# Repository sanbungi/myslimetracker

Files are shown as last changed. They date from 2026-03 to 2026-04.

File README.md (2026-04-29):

# 3次元移動解析装置 改 — 乾電池駆動 SlimeVR トラッカー

VR ヘッドセットだけでは追跡できない足や腰の動きを取るための、自作 SlimeVR 互換フルボディトラッカーです。両足先・両膝・腰・胸の6点に装着し、VRChat 上でのフルトラッキングを実現しています。

- 単3乾電池駆動 — リチウムポリマー電池のリスクを避け、安全で入手しやすい乾電池で動作
- 最上級 IMU 搭載 — SlimeVR 対応 IMU の中で最高性能の LSM6DSV を採用
- 低コスト — mocopi（5万円〜）に対し、6トラッカーを合計約2万円で制作
- 高い拡張性 — SlimeVR はトラッカー数に制限がなく、必要に応じて増設可能

<p align="center">
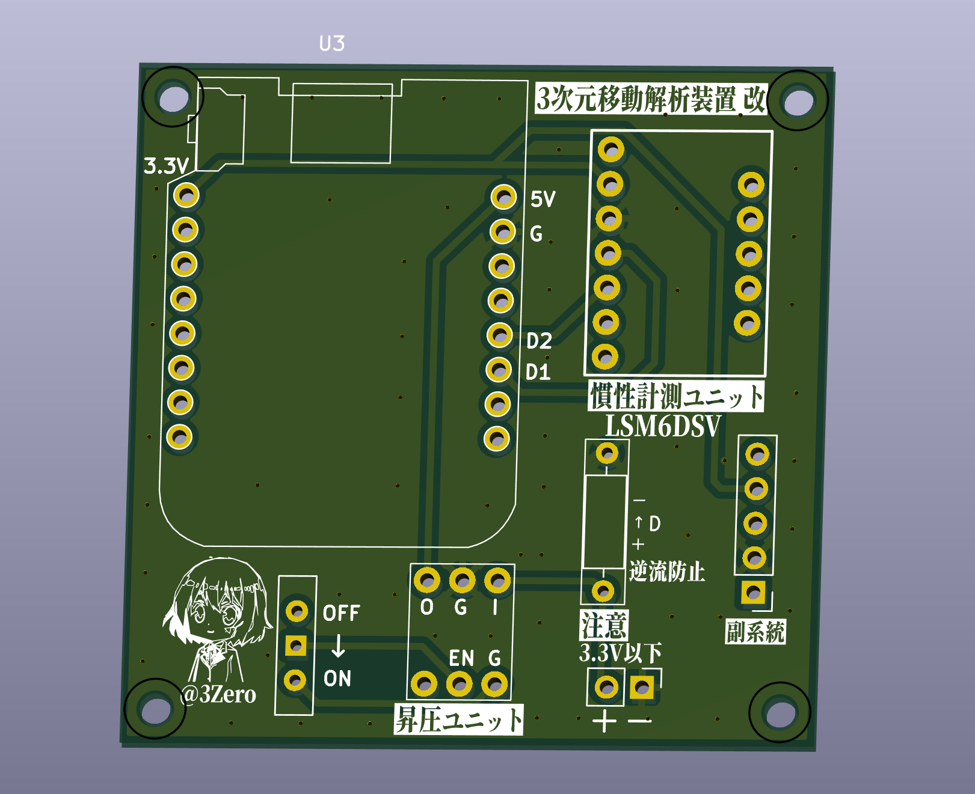
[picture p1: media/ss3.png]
現行版 PCB 3Dレンダリング
  
</p>

<p align="center"><i>現行基板の3Dレンダリング（KiCad）</i></p>

https://github.com/user-attachments/assets/3b7e9f30-eae3-4ba1-b326-60af60dc9e0d

<p align="center"><i>VRChat 内でのフルボディトラッキング動作</i></p>

## 乾電池へのこだわり

SlimeVR トラッカーの自作例はほとんどがリチウムポリマー電池を電源としていますが、本プロジェクトでは **単3乾電池** を採用しています。発火・膨張のリスクがなく、どこでも手に入り、近年は充電式乾電池（eneloop 等）も安価に出回っているため、ランニングコストも実用的です。

現行版は単3電池2本で動作し、昇圧 DC-DC コンバータで MCU・IMU に必要な電圧を供給しています。

## 基板設計

回路設計と基板レイアウトは KiCad で行い、製造は JLCPCB に発注しています。

| 部品 | 型番 | 役割 |
|---|---|---|
| MCU | Xiao ESP32-C3 | Wi-Fi 通信・SlimeVR ファームウェアの実行 |
| IMU | LSM6DSV | 6軸慣性計測（加速度 + ジャイロ） |
| 昇圧 DC-DC（現行） | 秋月電子 XCL103 キット | 単3x2 の電圧を 5V に昇圧 |
| 昇圧 DC-DC（次期） | TPS61291 | 単3x1 の電圧を 3.3V に昇圧 |

## 次期バージョン（WIP）

**単3乾電池1本** で駆動する次期基板を開発中です。昇圧回路・MCU・IMU を1枚の基板に統合し、さらなる小型化と軽量化を目指しています。就職活動のため一時中断中ですが、設計データは `new_prototype/` に格納しています。

---

## Gallery

### 6点トラッカーセット

<p align="center">
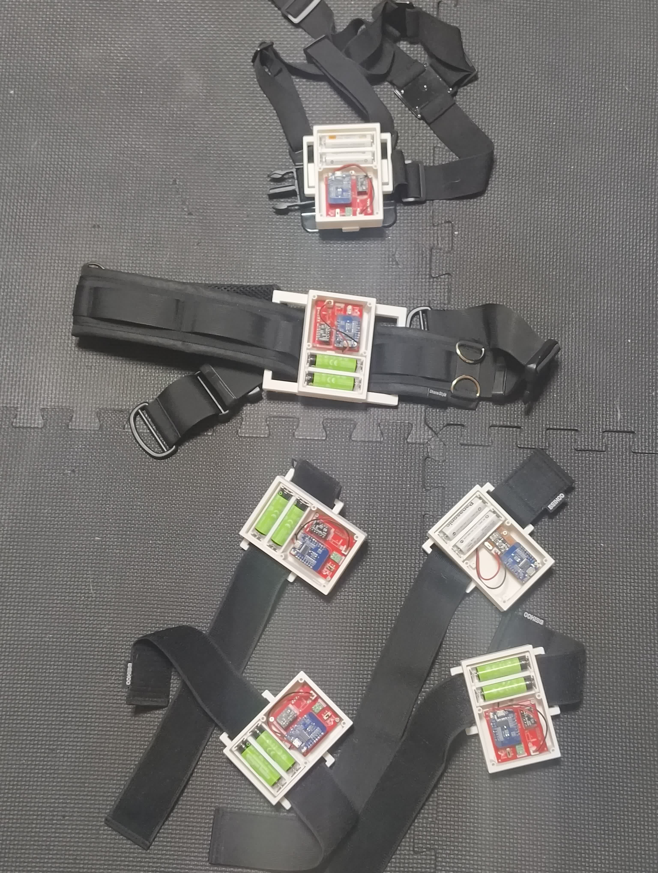
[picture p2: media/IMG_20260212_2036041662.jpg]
6点トラッカーセット実物
  
</p>

*実際に運用中の6点セット（両足先・両膝・腰・胸）*

### JLCPCB から届いた基板

<p align="center">
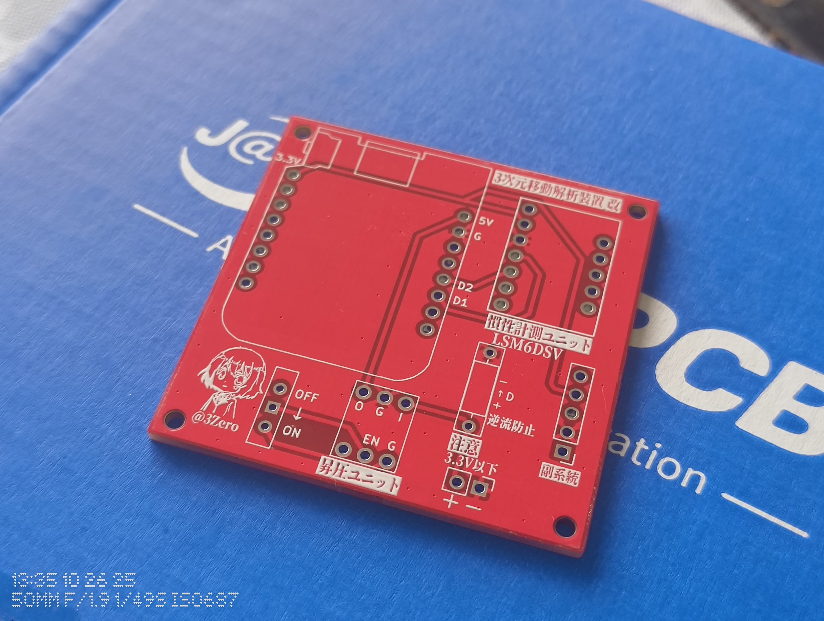
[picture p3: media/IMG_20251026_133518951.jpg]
JLCPCBから届いた基板
  
</p>

*JLCPCB に発注した基板の実物。*

### 次期基板 — 単3x1 実験（WIP）

<p align="center">
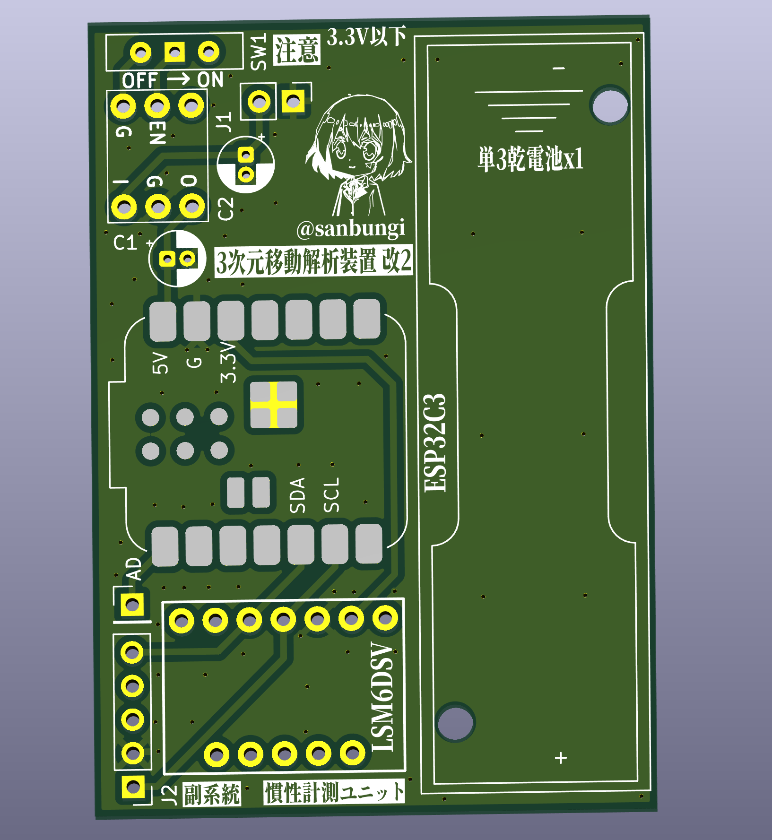
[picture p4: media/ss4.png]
次期版 PCB 3Dレンダリング
  
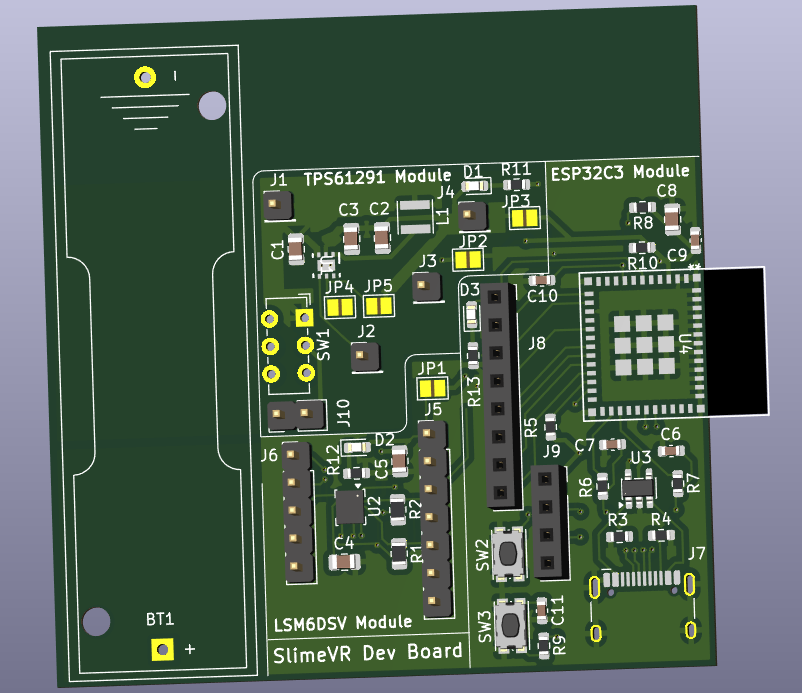
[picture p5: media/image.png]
SlimeVR Dev Board レンダリング
  
</p>

*左: 単3乾電池1本用の次期統合基板 / 右: 部品実装後のイメージ*

### 現行基板（単3x2）

<p align="center">
  現行版 PCB 3Dレンダリング
</p>

*KiCad 上での3Dレンダリング。昇圧ユニット・IMU・逆流防止回路を搭載。*

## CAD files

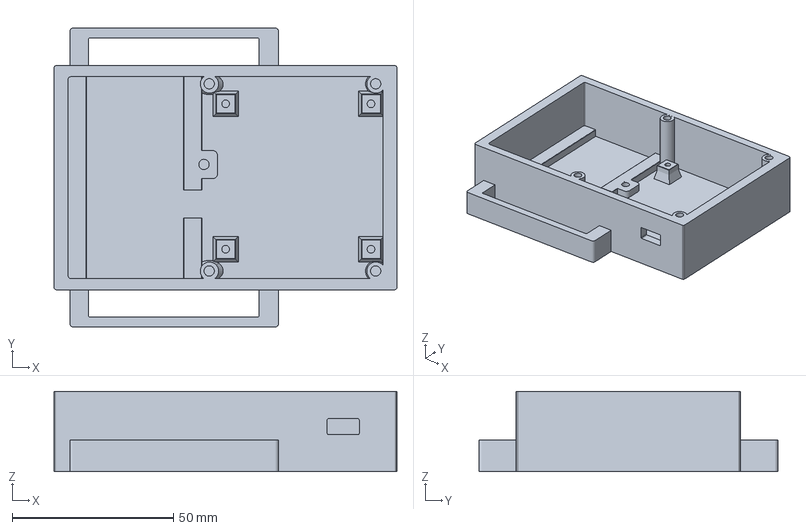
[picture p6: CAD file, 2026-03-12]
3dprint/tracker_2026.3mf
106.2 x 92.6 x 24.9 mm

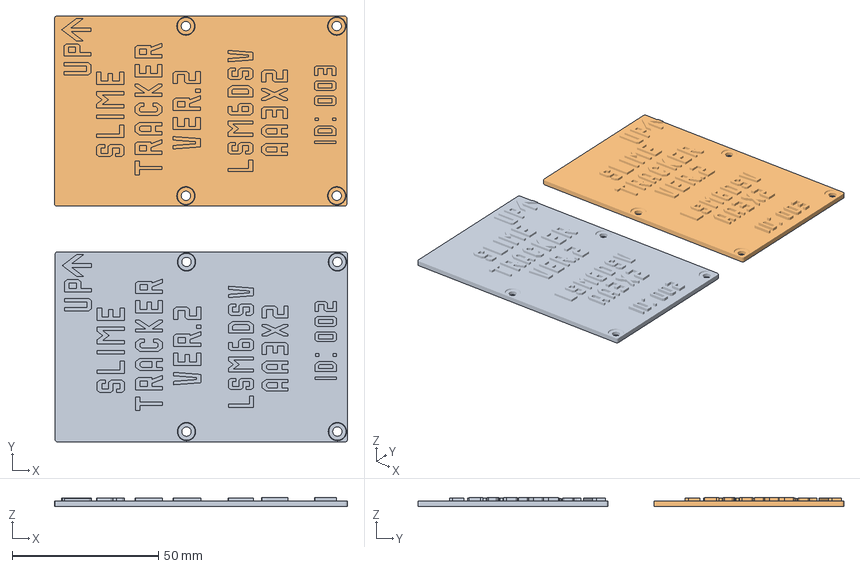
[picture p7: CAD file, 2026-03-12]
3dprint/cover.3mf
100.2 x 145.7 x 3.17 mm
box_re_002.stl
box_re_003.stl

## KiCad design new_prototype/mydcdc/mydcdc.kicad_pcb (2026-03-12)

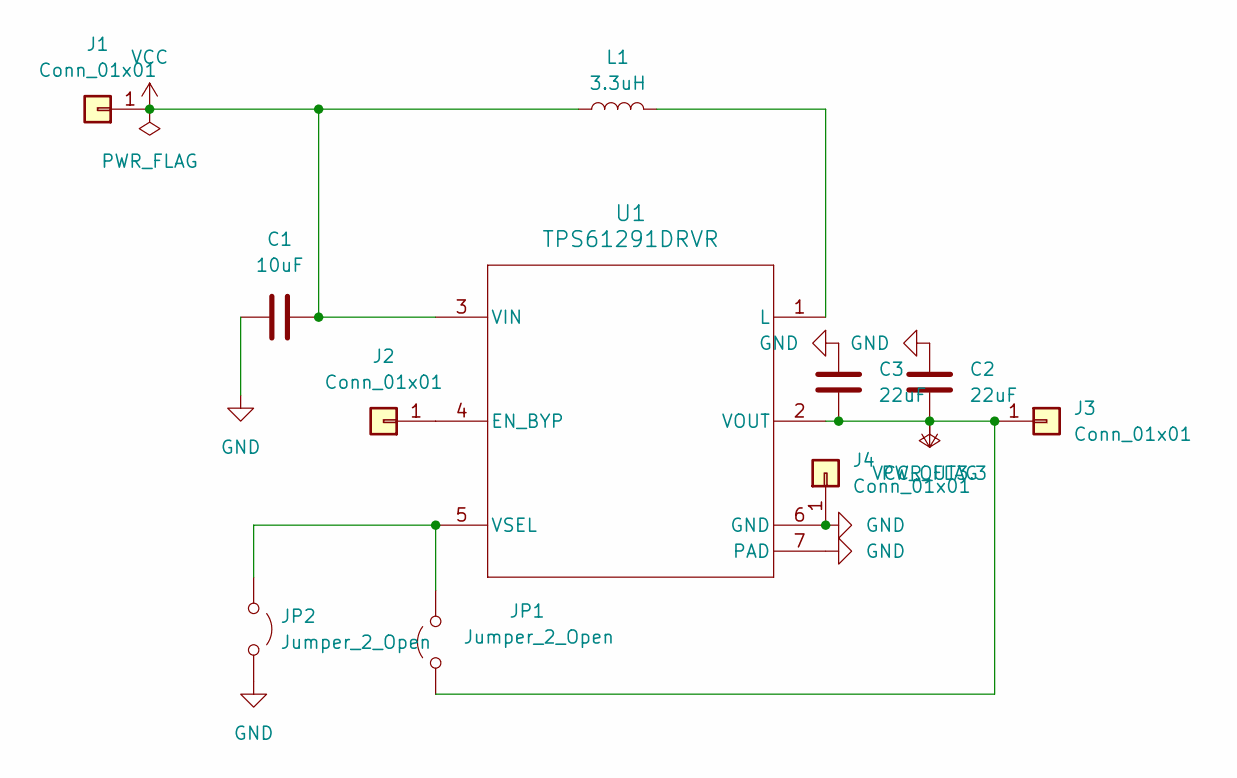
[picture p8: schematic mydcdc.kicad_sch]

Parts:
C1: 10uF; C_0805_2012Metric
C2, C3: 22uF; C_0805_2012Metric
J1, J2, J3, J4: Conn_01x01; PinHeader_1x01_P2.54mm_Vertical
JP1, JP2: Jumper_2_Open; SolderJumper-2_P1.3mm_Open_Pad1.0x1.5mm
L1: 3.3uH; L_Taiyo-Yuden_MD-3030
U1: TPS61291DRVR; DRV0006A

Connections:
GND: C1.1, C2.1, C3.1, J4.1, JP2.2 (B), U1.6 (GND), U1.7 (PAD); also elsewhere on the board
unnamed: J2.1, U1.4 (EN_BYP)
unnamed: JP1.1 (A), JP2.1 (A), U1.5 (VSEL)
unnamed: L1.2, U1.1 (L)
VCC: C1.2, J1.1, L1.1, U1.3 (VIN)
VCC_OUT3.3: C2.2, C3.2, J3.1, JP1.2 (B), U1.2 (VOUT)

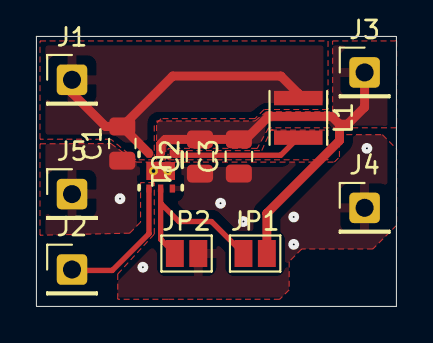
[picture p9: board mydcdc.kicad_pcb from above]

Board: 2 copper layers, 20.0 x 15.0 mm, 12 parts (0 on the bottom side), 6 nets.

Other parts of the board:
J5: Conn_01x01; PinHeader_1x01_P2.54mm_Vertical

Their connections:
GND: J5.1; also elsewhere on the board

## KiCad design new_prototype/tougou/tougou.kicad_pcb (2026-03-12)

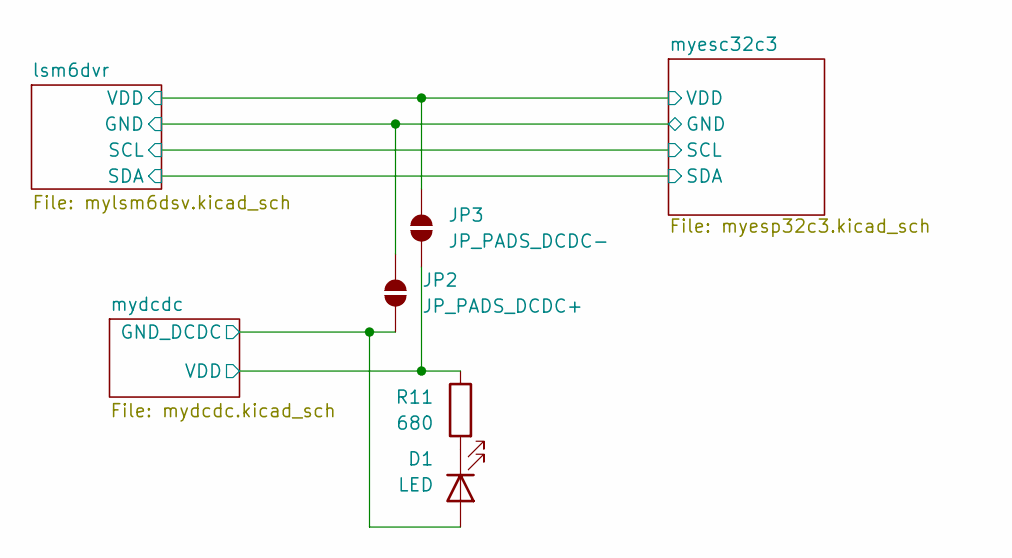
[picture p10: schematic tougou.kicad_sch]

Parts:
D1: LED; LED_0603_1608Metric
JP2: JP_PADS_DCDC+; SolderJumper-2_P1.3mm_Open_Pad1.0x1.5mm
JP3: JP_PADS_DCDC-; SolderJumper-2_P1.3mm_Open_Pad1.0x1.5mm
R11: 680; R_0603_1608Metric

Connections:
GND: JP2.2 (B); also elsewhere on the board
GND_DCDC: D1.2 (A), JP2.1 (A); also elsewhere on the board
unnamed: D1.1 (K), R11.2
VCC_OUT3.3: JP3.1 (A), R11.1; also elsewhere on the board
VDD: JP3.2 (B); also elsewhere on the board

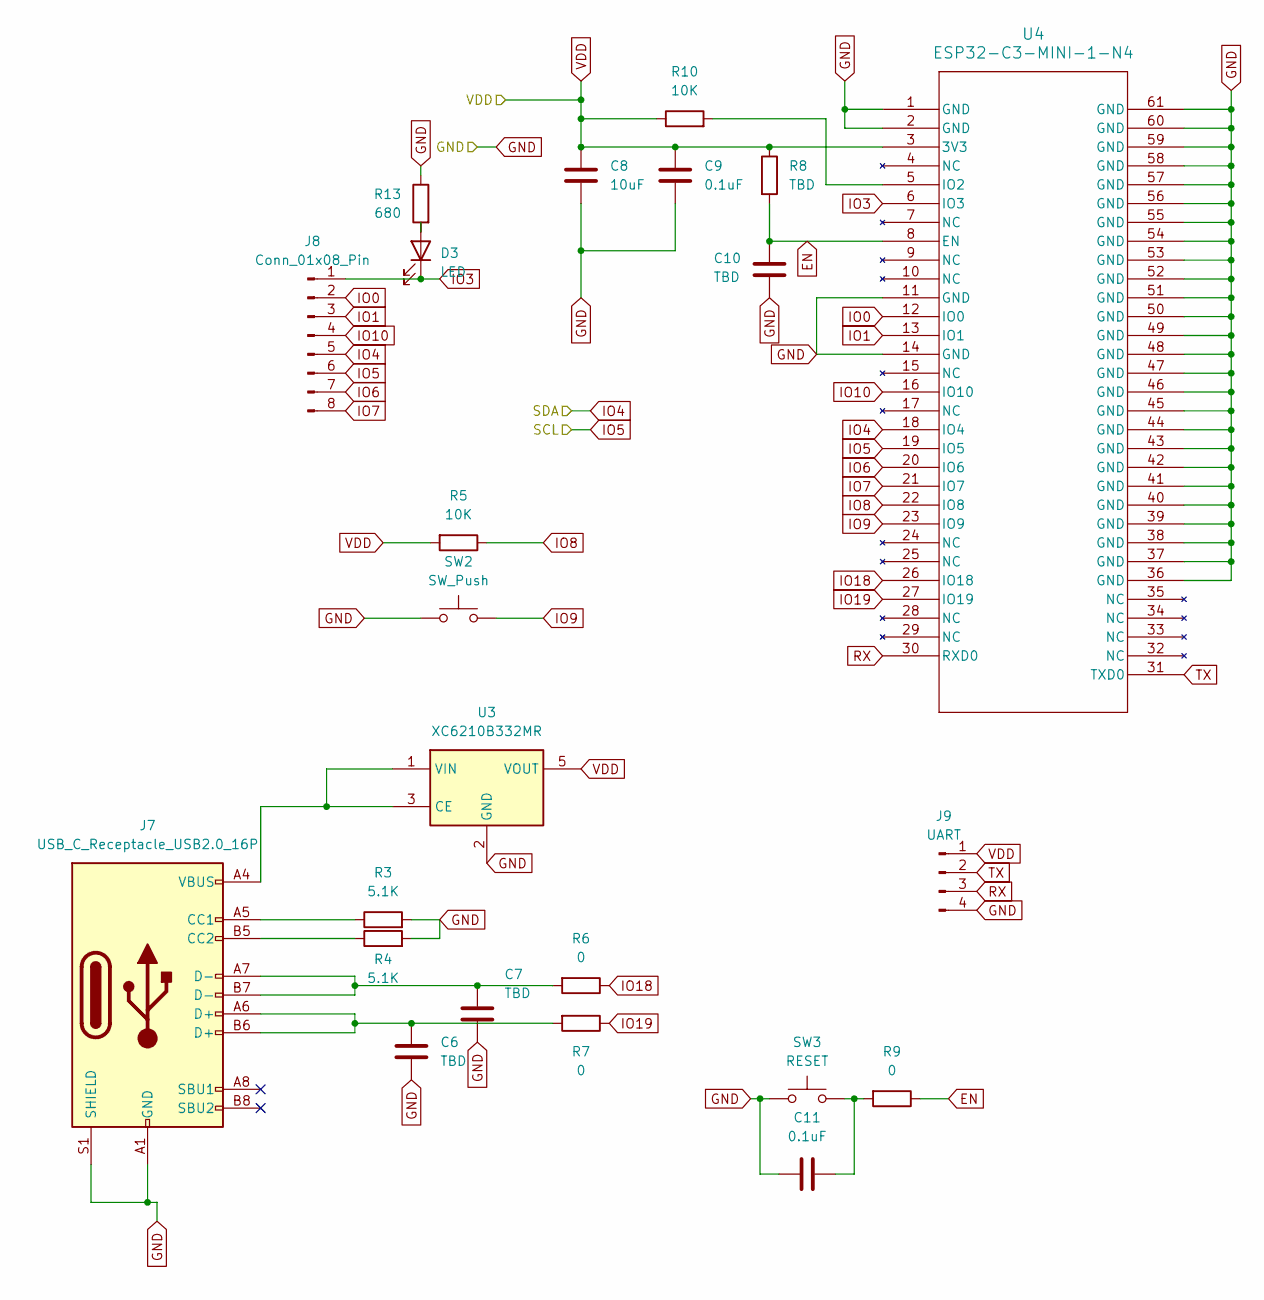
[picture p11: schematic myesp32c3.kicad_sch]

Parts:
C6, C7, C10: TBD; C_0603_1608Metric
C8: 10uF; C_0805_2012Metric
C9, C11: 0.1uF; C_0603_1608Metric
D3: LED; LED_0603_1608Metric
J7: USB_C_Receptacle_USB2.0_16P; USB_C_Receptacle_HCTL_HC-TYPE-C-16P-01A
J8: Conn_01x08_Pin; PinSocket_1x08_P2.54mm_Vertical
J9: UART; PinSocket_1x04_P2.54mm_Vertical
R3, R4: 5.1K; R_0603_1608Metric
R5, R10: 10K; R_0603_1608Metric
R6, R7, R9: 0; R_0603_1608Metric
R8: TBD; R_0603_1608Metric
R13: 680; R_0603_1608Metric
SW2: SW_Push; SW_Push_1P1T_NO_CK_KMR2
SW3: RESET; SW_Push_1P1T_NO_CK_KMR2
U3: XC6210B332MR; SOT-23-5
U4: ESP32-C3-MINI-1-N4; ESP32-C3-MINI-1_EXP

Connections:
EN: C10.1, R8.2, R9.1, U4.8 (EN)
GND: C6.2, C7.2, C8.2, C9.2, C10.2, C11.2, J7.A1 (GND), J7.A12 (GND), J7.B1 (GND), J7.B12 (GND), J7.S1 (SHIELD), J9.4, R3.2, R4.2, R13.1, SW2.1, SW3.1, U3.2 (GND), U4.1 (GND), U4.2 (GND), U4.11 (GND), U4.14 (GND), U4.36 (GND), U4.37 (GND), U4.38 (GND), U4.39 (GND), U4.40 (GND), U4.41 (GND), U4.42 (GND), U4.43 (GND), U4.44 (GND), U4.45 (GND), U4.46 (GND), U4.47 (GND), U4.48 (GND), U4.49 (GND), U4.50 (GND), U4.51 (GND), U4.52 (GND), U4.53 (GND), U4.54 (GND), U4.55 (GND), U4.56 (GND), U4.57 (GND), U4.58 (GND), U4.59 (GND), U4.60 (GND), U4.61 (GND); also elsewhere on the board
IO0: J8.2, U4.12 (IO0)
IO1: J8.3, U4.13 (IO1)
IO3: D3.1 (K), J8.1, U4.6 (IO3)
IO5: J8.6, U4.19 (IO5); also elsewhere on the board
IO6: J8.7, U4.20 (IO6)
IO7: J8.8, U4.21 (IO7)
IO8: R5.1, U4.22 (IO8)
IO9: SW2.2, U4.23 (IO9)
IO10: J8.4, U4.16 (IO10)
IO18: R6.1, U4.26 (IO18)
IO19: R7.1, U4.27 (IO19)
unnamed: C6.1, J7.A6 (D+), J7.B6 (D+), R7.2
unnamed: C7.1, J7.A7 (D-), J7.B7 (D-), R6.2
unnamed: C11.1, R9.2, SW3.2
unnamed: D3.2 (A), R13.2
unnamed: J7.A5 (CC1), R3.1
unnamed: J7.B5 (CC2), R4.1
unnamed: J7.A4 (VBUS), J7.A9 (VBUS), J7.B4 (VBUS), J7.B9 (VBUS), U3.1 (VIN), U3.3 (CE)
unnamed: R10.2, U4.5 (IO2)
RX: J9.3, U4.30 (RXD0)
SDA: J8.5, U4.18 (IO4); also elsewhere on the board
TX: J9.2, U4.31 (TXD0)
VDD: C8.1, C9.1, J9.1, R5.2, R8.1, R10.1, U3.5 (VOUT), U4.3 (3V3); also elsewhere on the board

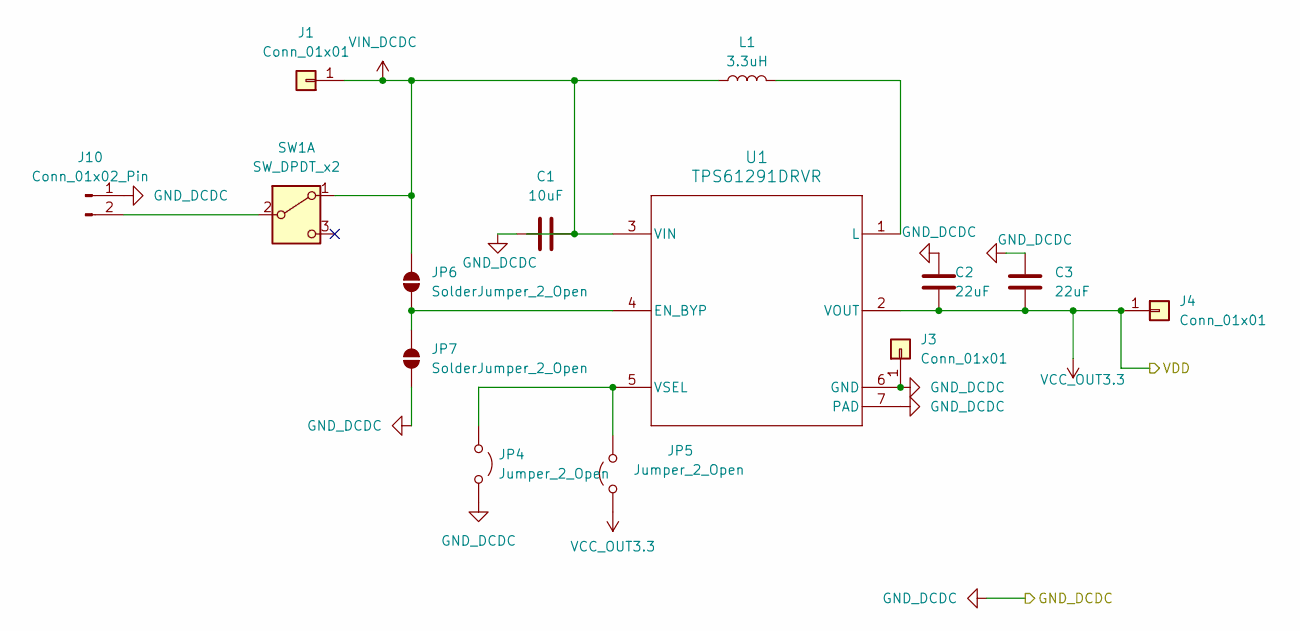
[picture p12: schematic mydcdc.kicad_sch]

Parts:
C1: 10uF; C_0805_2012Metric
C2, C3: 22uF; C_0805_2012Metric
J1, J3, J4: Conn_01x01; PinHeader_1x01_P2.54mm_Vertical
J10: Conn_01x02_Pin; PinHeader_1x02_P2.54mm_Vertical
JP4, JP5: Jumper_2_Open; SolderJumper-2_P1.3mm_Open_Pad1.0x1.5mm
JP6, JP7: SolderJumper_2_Open; SolderJumper-2_P1.3mm_Open_Pad1.0x1.5mm
L1: 3.3uH; L_Taiyo-Yuden_MD-3030
SW1: SW_DPDT_x2; SW_E-Switch_EG1271_SPDT
U1: TPS61291DRVR; DRV0006A

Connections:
GND_DCDC: C1.1, C2.1, C3.1, J3.1, J10.1, JP4.2 (B), JP7.1 (A), U1.6 (GND), U1.7 (PAD); also elsewhere on the board
unnamed: J10.2, SW1.2 (B)
unnamed: JP4.1 (A), JP5.1 (A), U1.5 (VSEL)
unnamed: JP6.1 (A), JP7.2 (B), U1.4 (EN_BYP)
unnamed: L1.2, U1.1 (L)
VCC_OUT3.3: C2.2, C3.2, J4.1, JP5.2 (B), U1.2 (VOUT); also elsewhere on the board
VIN_DCDC: C1.2, J1.1, JP6.2 (B), L1.1, SW1.1 (A), U1.3 (VIN)

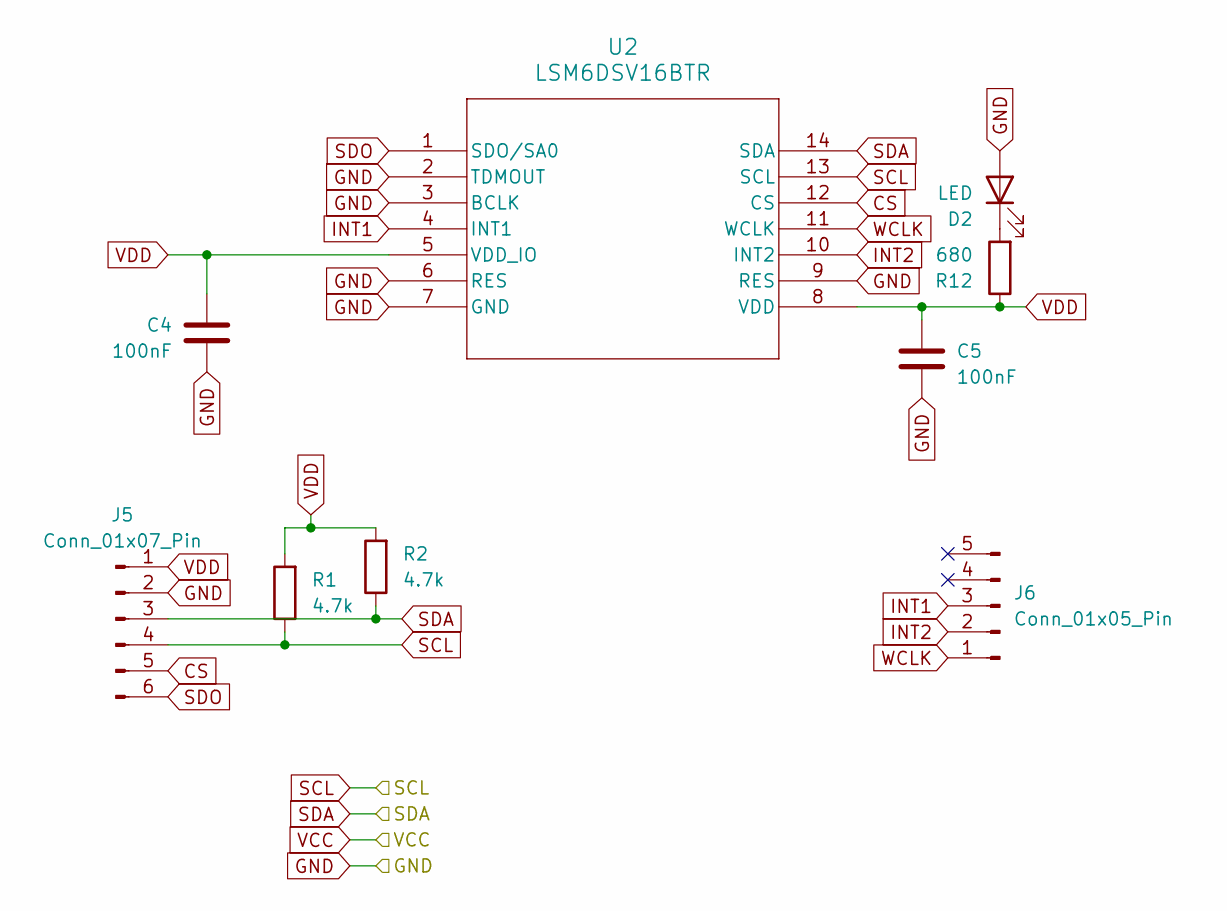
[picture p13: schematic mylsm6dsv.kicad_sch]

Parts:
C4, C5: 100nF; C_0805_2012Metric
D2: LED; LED_0603_1608Metric
J5: Conn_01x07_Pin; PinHeader_1x07_P2.54mm_Vertical
J6: Conn_01x05_Pin; PinHeader_1x05_P2.54mm_Vertical
R1, R2: 4.7k; R_0805_2012Metric
R12: 680; R_0603_1608Metric
U2: LSM6DSV16BTR; LGA-14_3x2.5mm_P0.5mm_LayoutBorder3x4y

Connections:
CS: J5.5, U2.12 (CS)
GND: C4.2, C5.2, D2.2 (A), J5.2, U2.2 (TDMOUT), U2.3 (BCLK), U2.6 (RES), U2.7 (GND), U2.9 (RES); also elsewhere on the board
INT1: J6.3, U2.4 (INT1)
INT2: J6.2, U2.10 (INT2)
IO5: J5.4, R1.1, U2.13 (SCL); also elsewhere on the board
unnamed: D2.1 (K), R12.2
SDA: J5.3, R2.1, U2.14 (SDA); also elsewhere on the board
SDO: J5.6, U2.1 (SDO/SA0)
VDD: C4.1, C5.1, J5.1, R1.2, R2.2, R12.1, U2.5 (VDD_IO), U2.8 (VDD); also elsewhere on the board
WCLK: J6.1, U2.11 (WCLK)

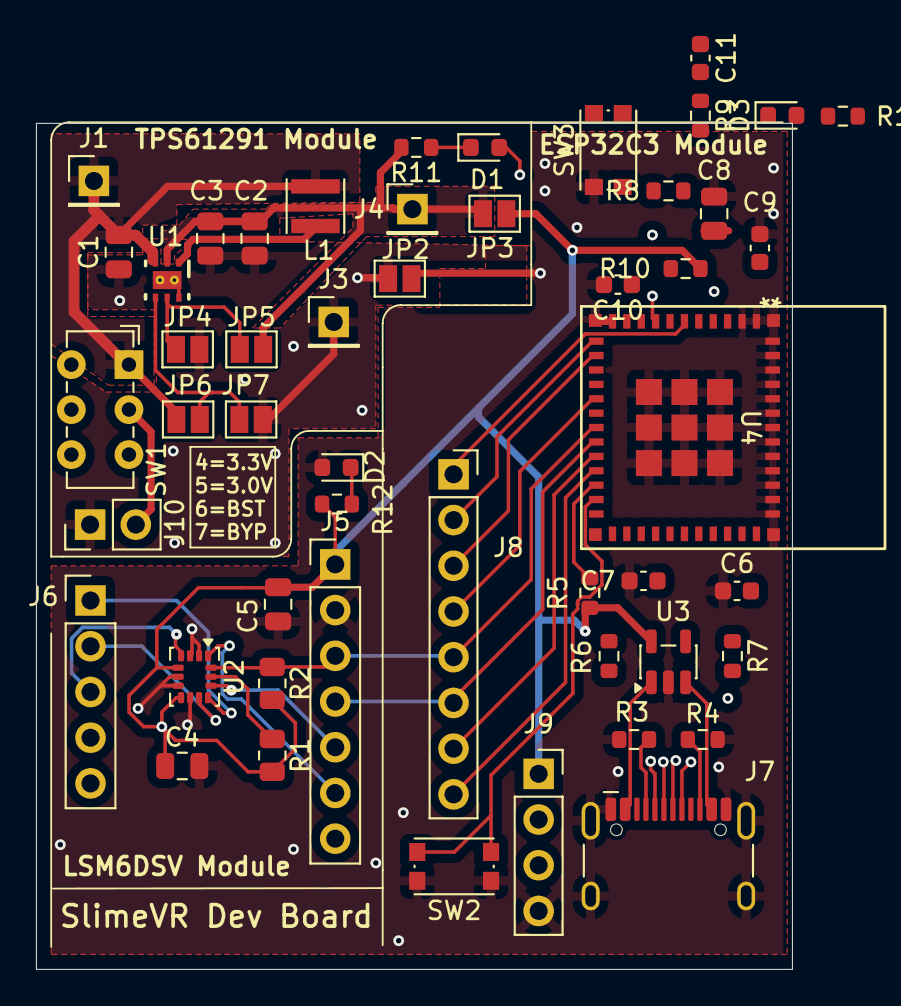
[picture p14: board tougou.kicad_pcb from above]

Board: 2 copper layers, 42.0 x 47.0 mm, 50 parts (0 on the bottom side), 39 nets.

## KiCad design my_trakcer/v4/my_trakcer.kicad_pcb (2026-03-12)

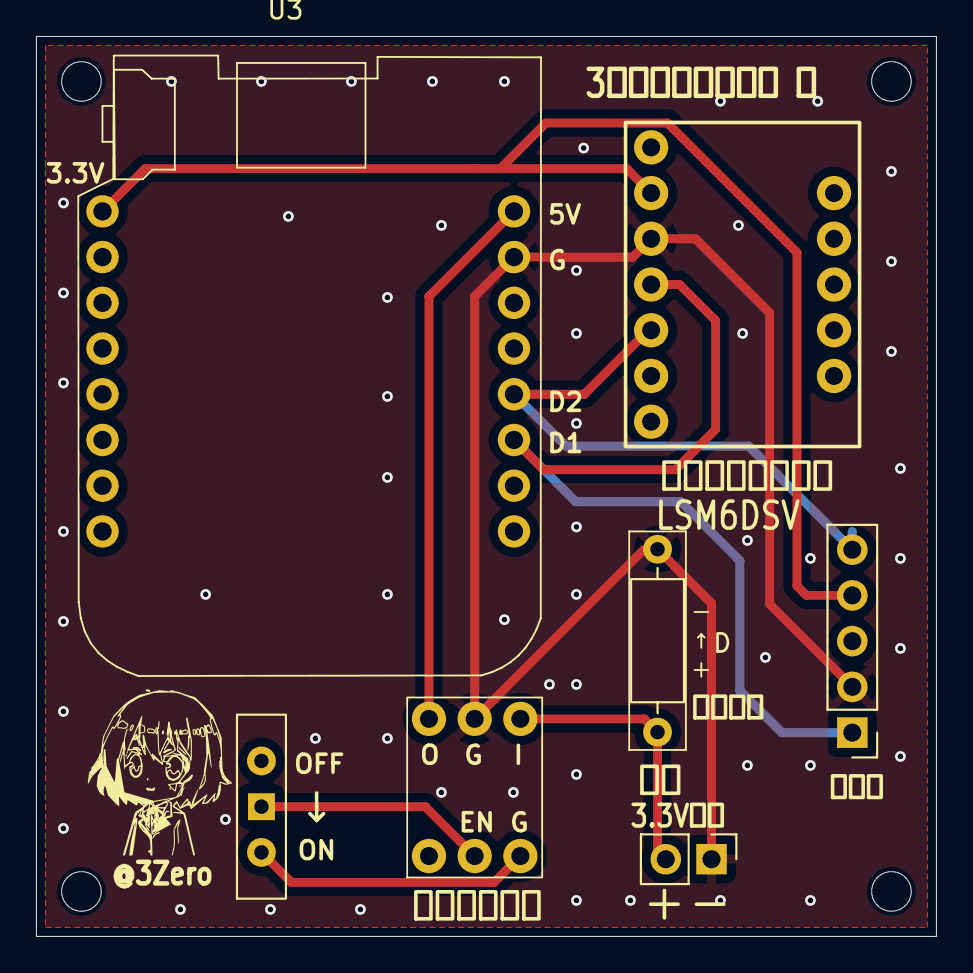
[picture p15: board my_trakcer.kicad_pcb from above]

Board: 2 copper layers, 50.0 x 50.0 mm, 7 parts (0 on the bottom side), 8 nets.

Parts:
D: D; L_Axial_L6.6mm_D2.7mm_P10.16mm_Horizontal_Vishay_IM-2
D1: DCDC; AE-XCL103-5V0
J1: VIN; PinHeader_1x02_P2.54mm_Vertical
J2: 2nd; PinHeader_1x05_P2.54mm_Vertical
SW1: SW1; SW_Slide-03_Wuerth-WS-SLTV_10x2.5x6.4_P2.54mm
U1: LSM6DSV
U3: WeMos_mini; D1_mini_board

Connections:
3.3V: J2.4, U1.2 (3V3), U3.16 (3.3V)
GND: D.1 (K), D1.5 (GND), J1.1, J2.2, U1.3 (GND), U3.2 (GND)
unnamed: D1.2 (EN), SW1.1 (A)
unnamed: D1.4 (OUT), U3.1 (5V)
unnamed: D.2 (A), D1.6 (IN), J1.2
unnamed: D1.3 (GND), SW1.2 (B)
SCL: J2.1, U1.4 (SCL), U3.6 (D1)
SDA: J2.5, U1.5 (SDA), U3.5 (D2)

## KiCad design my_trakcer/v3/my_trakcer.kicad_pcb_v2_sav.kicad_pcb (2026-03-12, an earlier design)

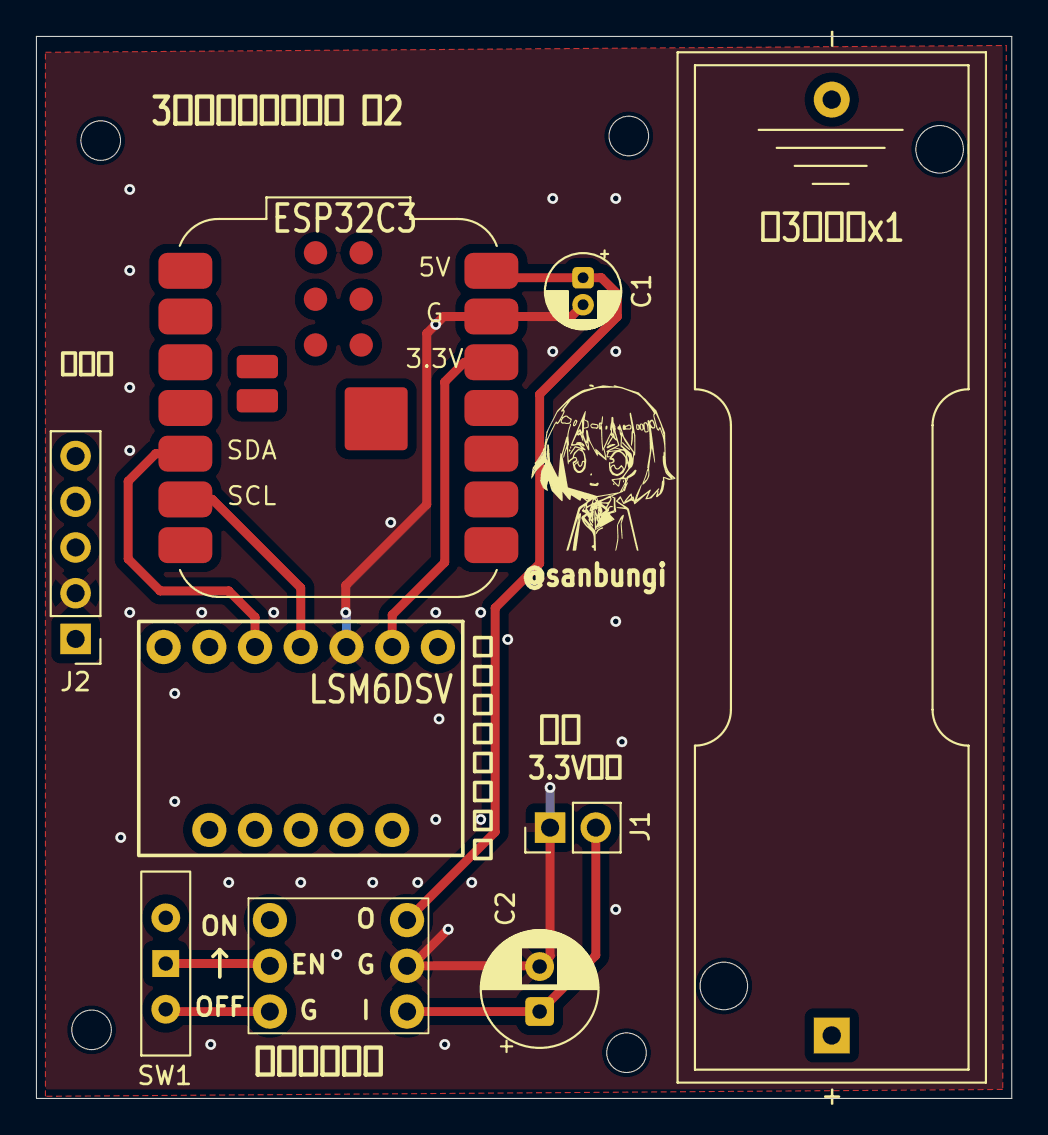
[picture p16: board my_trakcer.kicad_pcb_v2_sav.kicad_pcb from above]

Board: 2 copper layers, 54.2 x 59.0 mm, 8 parts (0 on the bottom side), 8 nets.

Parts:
C1: C; CP_Radial_D4.0mm_P1.50mm
C2: C; CP_Radial_D6.3mm_P2.50mm
D2: AE-XCL103-5V02
J1: VIN; PinHeader_1x02_P2.54mm_Vertical
J2: 2nd; PinHeader_1x05_P2.54mm_Vertical
SW1: SW1; SW_Slide-03_Wuerth-WS-SLTV_10x2.5x6.4_P2.54mm
U2: XIAO-ESP32-C3-DIP; MCU_Seeed_ESP32C3
U3: LSM6DSV

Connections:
3.3V: J2.4, U2.12 (3V3), U3.2 (3V3)
GND: C1.2, C2.2, D2.5 (GND), J1.1, J2.2, U2.13 (GND), U3.3 (GND)
unnamed: D2.2 (EN), SW1.1 (A)
unnamed: C1.1, D2.4 (OUT), U2.14 (VBUS)
unnamed: C2.1, D2.6 (IN), J1.2
unnamed: D2.3 (GND), SW1.2 (B)
SCL: J2.1, U2.6 (GPIO7_D5_SCL), U3.4 (SCL)
SDA: J2.5, U2.5 (GPIO6_D4_SDA), U3.5 (SDA)

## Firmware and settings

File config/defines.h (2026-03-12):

#define IMU IMU_LSM6DSV
#define SECOND_IMU IMU
#define BOARD BOARD_WEMOSD1MINI
#define IMU_ROTATION DEG_90
#define SECOND_IMU_ROTATION DEG_90

#define PRIMARY_IMU_OPTIONAL false
#define SECONDARY_IMU_OPTIONAL true

#define MAX_IMU_COUNT 1

#ifndef IMU_DESC_LIST
#define IMU_DESC_LIST \
    IMU_DESC_ENTRY(IMU,        PRIMARY_IMU_ADDRESS_ONE,   IMU_ROTATION,        PIN_IMU_SCL, PIN_IMU_SDA, PRIMARY_IMU_OPTIONAL,   PIN_IMU_INT) 

#endif

// Battery monitoring options (comment to disable):
// BAT_EXTERNAL for ADC pin, BAT_INTERNAL for internal - can detect only low battery, BAT_MCP3021 for external ADC
#define BATTERY_MONITOR BAT_INTERNAL
#define BATTERY_SHIELD_RESISTANCE 200 //130k BatteryShield, 180k SlimeVR or fill in external resistor value in kOhm

#define PIN_IMU_SDA D2
#define PIN_IMU_SCL D1
#define PIN_IMU_INT D5
#define PIN_IMU_INT_2 D6
#define PIN_BATTERY_LEVEL A0

// LED無効化（省電力化）- LED_OFF = 255
//#define LED_PIN 255

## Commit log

2026-03-12 kicadファイルを追加
    [2026_v2.kicad_pcb, my_trakcer.kicad_pcb, my_trakcer.kicad_pcb_v2.kicad_pcb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]
2026-03-12 3dプリント用ファイルを追加
    [cover.3mf, tracker_2026.3mf]
2026-03-12 slivemr要定義ファイル
2026-03-12 新規プロトタイププロジェクトをコピー
    [mydcdc.kicad_pcb, mydcdc.kicad_sch, myesp32c3.kicad_sch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]
2026-03-12 紹介用画像
